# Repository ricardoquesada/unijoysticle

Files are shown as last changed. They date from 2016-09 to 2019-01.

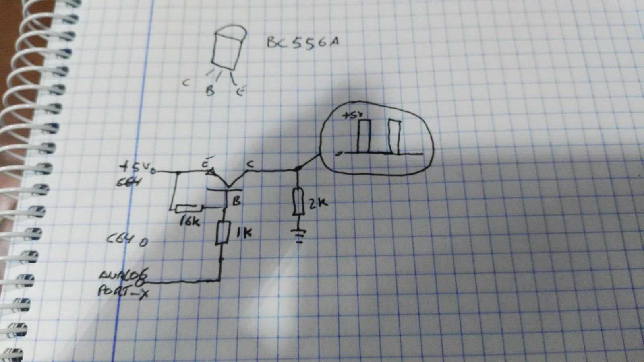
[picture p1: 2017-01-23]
schematic/unijoysticle_ultimate/maniako_filter.jpg

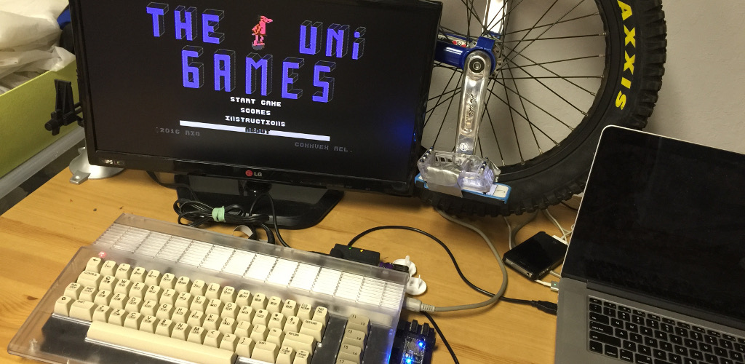
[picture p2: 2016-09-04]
client_android/store_images/feature_graphic.jpg

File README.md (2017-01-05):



# The UniJoystiCle

UniJoystiCle™

The UniJoystiCle, the ultimate unicycle simulator.

It allows you to play Commodore 64 [unicycle video games](https://github.com/ricardoquesada/c64-the-uni-games) with real unicycles. Unique immersive experience, much better than VR.

This repository contains:

* the [schematic + PCB board](https://github.com/ricardoquesada/unijoysticle/tree/master/schematic) to build your own Wi-Fi receiver
* the [firmware](https://github.com/ricardoquesada/unijoysticle/tree/master/esp8266_firmware) that runs on the Wi-Fi receiver
* the [iOS client](https://github.com/ricardoquesada/unijoysticle/tree/master/client_ios) / [Android client](https://github.com/ricardoquesada/unijoysticle/tree/master/client_android) / [Desktop client](https://github.com/ricardoquesada/unijoysticle/tree/master/client_desktop): they send the packets to the Wi-Fi receiver

UniJoystiCle v0.4

## Further info

* [Documentation](DOCUMENTATION.md)
* [Home page](http://retro.moe/unijoysticle)

## Videos

The Uni Games v0.4 (https://www.youtube.com/watch?v=ZLAgooXx4bo)

Game Controllers (https://www.youtube.com/watch?v=2lZSAKbrHTo)

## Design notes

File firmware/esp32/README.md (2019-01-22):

# Unijoysticle v2.0

Unijoysticle + bluetooth.

## About

Use modern bluetooth gamepads / mouse in old computers like the Commodore 64, Atari ST, Amiga 500, Apple 2, Tandy 1000, IBM PC Jr., Atari 800, etc.

## Status

Early develop stages. PoC working on PC. Need the rest.

- firmware works on PC.
- missing all the rest.

## Want to help ?

- Download libusb: https://libusb.info/ (needed to test on PC with bluetooth dongle).
- Download BlueKitchen: https://github.com/bluekitchen/btstack
- Download Unijoysticle code: https://gitlab.com/ricardoquesada/unijoysticle
- Get any bluetooth gamepad (iOS, Android, Xbox tested. PS4 not supported ATM)
- For ESP32:
  - Download ESP-IDF: https://github.com/espressif/esp-idf
  - Get an ESP32 module, like [the MH-ET Live][1] which is pin-compatible with [Wemos D1 Mini][2] (used by Unijoysticle v0.4.2 PCB).

### Compile BTstack

#### For PC/Linux/Mac development

- Install the Bluetooth USB dongle on your PC/Mac/Linux
- libusb: Compile and install. Don't use `master` tip-of-tree if you are on macOS. Use 1.0.22 or earlier
- bluekitchen: Compile the libusb port to make sure everything works.

```sh
$ cd src/btstack/port/libusb
$ make
$ ./gap_inquiry
```

Put your gamepad in bluetooth discovery mode and you should see it.

#### For ESP32 development
```sh
$ cd src/btstack/port/esp32
$ ./integrate_btstack.py
$ cd example/gap_inquiry
$ make menuconfig
$ make flash monitor
```
And just in case, read the `README.md` that is in the `src/btstack/port/esp32` folder.

Put your gamepad in bluetooth discovery mode and you should see it.

### Compile Unijoysticle

Once you know that BTStack is working as expected, you can try with the UniJoystiCle code.

For PC/Linux/Mac development:
```sh
$ cd src/unijoysticle/firmware/esp32/tools
$ make
./unijoysticle
```

For ESP32 development:
```sh
$ cd src/unijoysticle/firmware/esp32
$ make menuconfig
$ make flash monitor
```

Put the gamepad in discovery mode. The gamepad should be recognized and when you press buttons, you should see them on the console.

## What works:

- PC + Bluetooth dongle. Ideal for rapid development. Eastier to test new Bluetooth features and debug.
- Works on ESP32 as well
- It supports up until 4 gamepads at the same time.
- Discovery/Connect/Disconnect/Reconnects works
- Parses HID and identifies all possible gamepad buttons / pads / hats.

## What's missing

### Firmware:
- Create mapping code. Something that correctly maps the different gamepad buttons to the desired ones.
- Support Class / Extended modes:
   - Mode Classic: traditional modes with 1 or 2 gamepads (like one or two joysticks)
   - Mode extended: one gamepad controls 2 joysticks
- Test everything on esp32
  - Disable non required features like WiFi that it takes less current.
- Support mouse/pads: ideally a bluetooth mouse could be used.

### Hardware

- it is possible that the board could get current from the c64/atari's joystick ports?
- design new board, if possible one that doesn't use devkits
- lines for the C64 / Atari pots
- PC Jr. / Tandy 1000 / Apple II: investigate, they use analog lines

### Mobile application

- [Optional]: Simple Bluetooth application that connects to the host and allow us to configure it
  and see its status, etc.

[1]: https://www.aliexpress.com/item/MH-ET-LIVE-ESP32-MINI-KIT-WiFi-Bluetooth-Internet-of-Things-development-board-based-ESP8266-Fully/32819107932.html
[2]: https://wiki.wemos.cc/products:d1:d1_mini

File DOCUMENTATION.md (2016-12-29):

# The UniJoystiCle™ Documentation

* [About](#about)
* [The WiFi Device](#the-wifi-device)
* [The Smartphone client controller](#smartphone-client-application)
* [The Desktop client controller](#desktop-client-application)
* [The Protocol](#the-protocol)
* [Building the WiFi Device](#building-the-wifi-device)
* [Firmware Options](#firmware-options)
* [Troubleshooting](#troubleshooting)

## About
The UniJoystiCle is a unicycle simulator for the Commodore 64, and much more! It allows you to control the joystick lines remotely, with anything that you have in mind like:

* play c64 games using modern game controllers (Xbox, iOS or Android game controllers)
* play [The Uni Games](https://github.com/ricardoquesada/c64-the-uni-games), a c64 unicycle game, using a real unicycle
* automate your home from the C64 with the [Commodore Home](https://retro.moe/2016/10/31/retro-challenge-commodore-home/)
* and more!

It consists of two major parts:

* The UniJoystiCle WiFi device
* The UniJoystiCle client application: iOS, Android, Mac, Windows and Linux

## The WiFi device



The WiFi device goes attached to the Commodore 64, and is the one that generates the real joystick movements. It does so by opening/closing the joystick lines.

In order to work it needs power. Unfortunately the C64 joystick ports DON'T have enough current to power it. The options to power it are:

* Using the barrel jack:
  * a +5v DC with at least 320mA
  * Examples:
    * Getting power from the Datasette port [with a custom cable](http://store.go4retro.com/c2n-power/) (recommended, but might need a [PSU with enough amps](http://personalpages.tds.net/~rcarlsen/custom%20ps.html))
* Using the micro USB socket:
  * It can be connected to a computer
  * or using a wall charger



### Booting the WiFi device

* DO NOT plug the UniJoystiCle WiFi device to the Commodore 64 yet (if you plug it, you won't break anything, it is that it just might not boot)
* Power the UniJoystiCle WiFi device (see above)
* Wait a few seconds and you should see one LED. That means that the device booted, and you can connect to it.
  * If you don't see the one LED, please go to [Troubleshooting](#troubleshooting)
* Now, you can plug it to the Commodore 64

By default, the WiFi device will start in Access Point mode, and will create a WiFi network named "unijoysticle-xxyyzz". From your smartphone Settings, connect to it...:



...and then launch the UniJoystiCle smartphone app.

## Smartphone Client Application

The client application can be download for free from the App Store / Google Play:

<a href='https://play.google.com/store/apps/details?id=moe.retro.unijoysticle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'>Get it on Google Play</a>

It sends "joystick commands" to the WiFi device. These commands are regular joystick movements: _Up_, _Down_, _Left_, _Right_ and _Fire_. It can send one or multiple commands at the time.

There are five modes: _UniJoystiCle mode_, _D-pad mode_, _Commando mode_, _Gyruss mode_ and _Commodore Home mode_.



### UniJoystiCle mode

      

In this mode, the joystick commands are generated from the smartphone's accelerometer. The accelerometer detects acceleration in the three coordinates: X, Y and Z. If we attach an accelerometer (in this case the smartphone) to a unicycle (or bike) pedal, and we measure the accelerometer's data while we pedal, we will notice that the X and Z axis generates data similar to a sine and cosine.



And if we put those values in cartesian coordinates (eg: Accelerometer(Z) = Y axis, and Accelerometer(X) = X axis), we will have something similar to a circle.



And if we calculate the arctangent (`atan2()`) value of sin/cosine we get the angle. And with the angle we can simulate the joystick movements. We divide the circle in 8 segments, and assign a joystick movement to each segment. Eg:



There are no such things as "joystick diagonal commands". So in order to simulate the top-right diagonal, we just send the "top" and "right" joystick movements at the same time.

From the graphic we can deduce that:
<p style="padding-left: 30px;"><strong>One pedal revolution == one joystick "revolution"</strong></p>
But it is possible to change that ratio. For example, we can change it to "One pedal revolution == <strong>two</strong> joystick revolutions". Just go to settings and do:



A ratio of 2.0 will divide the circle in 16 segments (8 segments * 2.0 ratio == 16 segments), and what will happen is that:
<p style="padding-left: 30px;">One pedal revolution == Two joystick revolutions</p>



This is useful to:

* Increase your speed when you have an slow unicycle (eg: long cranks or big wheel size), or you don't pedal fast enough
* You want to play face-to-face with another rider, but one has an slower unicycle

__Firing:__ In order to _fire_, you have to hop. Settings has a "Jump Threshold" settings that is used to control how hard you have to hop.

__Compatibility:__ This mode is compatible with multiple sports games like:

* [The Uni Games](https://github.com/ricardoquesada/c64-the-uni-games) (in fact this mode was created to play this game)
* Sports games like [Hypersports](http://gamebase64.com/game.php?id=3666&d=18&h=0), [Decathon](http://gamebase64.com/game.php?id=2057&d=18&h=0), etc.
* [C64anabalt](http://www.rgcd.co.uk/2011/12/c64anabalt-c64-2011.html), and other jump-only-games
* and more

__Video:__ [Using a unicycle to play The Uni Games ](https://www.youtube.com/watch?v=w2cdoTU-GJU)

__Video:__ [Using one foot to play C64anabalt](https://www.youtube.com/watch?v=n7p1p53uisk)

### D-pad mode



This mode converts the smartphone in a virtual D-pad. Just press the arrows for joysticks movements, and the circle to fire.

__Compatibility:__

* Any game can be played in this mode.

__Using this mode:__ [YouTube video](https://youtu.be/RhEGogreM0E)

### D-pad + Game Controllers



This is the same D-pad mode as before. But if you <a href="http://www.howtogeek.com/242223/how-to-use-a-physical-game-controller-with-an-iphone-ipad-or-android-device/">connect any Game Controller to your smartphone</a> (for iOS it supports both <a href="https://afterpad.com/mficontrollers/">MFi</a> and <a href="https://www.ionaudio.com/products/details/icade">iCade</a> controllers; for Android it supports official controllers as well as OUYA ones), it will automatically detect it. And with it you can control the virtual D-pad giving you a great gaming experience.

You can configure it to:

* Use Button "B" to jump. When enabled, it will disable to "Up" D-pad arrow
* Swap Buttons "A" and "B" (swaps Jump and Shoot buttons)



__Compatibility:__

* Any game can be played in this mode.
* Optimized for platformer games like [Giana Sisters](http://gamebase64.com/game.php?id=3275&amp;d=18&amp;h=0), [Super Bread Box](http://gamebase64.com/game.php?id=24140&amp;d=18&amp;h=0), [Bubble Bobble](http://gamebase64.com/game.php?id=1138&amp;d=18&amp;h=0), etc.

__Using this mode:__ [YouTube video](https://www.youtube.com/watch?v=0cdgaYVYaao)

__Which controller should you use:__

For iOS:
* For MFi controllers, try here: [AfterPad](https://afterpad.com/mficontrollers/">https://afterpad.com/mficontrollers/). The [Nimbus SteelSeries](https://afterpad.com/steelseries-nimbus-the-afterpad-review/) is good. DO NOT get the Status SteelSeries.
* For iCade controlles, try here: [iCade Controllers](http://retrorgb.com/icadecontrollers.html). The ["original" iCade](http://retrorgb.com/icade.html) is good.

For Android:
* Any Game Controller that supports __the Android protocol__. See [reviews here](http://www.androidauthority.com/best-bluetooth-gaming-controllers-403184/) [and here](https://www.slant.co/topics/2074/~third-party-game-controllers-for-android)
* OUYA Game Controllers (they are not that great though). [Get it here](http://www.ebay.com/sch/i.html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)
* Notes:
  * Amazon Fire Game Controllers support the Android protocol
  * Moga Game Controllers support the Android protocol [when in "B" mode](https://gavinsgadgets.com/2016/03/21/how-to-connect-a-moga-pro-power-bluetooth-game-controller-with-the-samsung-galaxy-s7/)
  * WiFi-Direct game controllers are supported as well, like the NVIDIA SHIELD, or the Amazon Fire 2nd gen. But since most smartphones don't support WiFi-Direct, you should install the Android UniJoystiCle app into WiFi-Direct-enabled devices, like the Amazon Fire TV, or the NVIDIA SHIELD Android TV.

### Commando mode + Game Controllers



In this mode you control both joysticks at the same time. A game controller is needed for this. Can't be played with the "virtual" dpad.
It is called "Commando" mode, since it allows you to play games like Commando, Turrican II or Dropzone since:

* The dpad and the left stick are mapped to Joystick #2 direction movements
* The right stick is mapped to Joysticke #1 directional movements
* Button A is mapped to Joystick #2 Fire
* Button B is mapped to Joystick #1 Fire
* Button X is mapped to Joystick #1 Down
* Button Y is mapped to Joystick #1 Rigth

For example:

 * in Commando you can throw grenades by pressing button B.
 * in Turrican II you can trigger the power lines by pressing button B, and trigger the super weapon by pressing button A and B simultaneously
 * in Dropzone you can use button B to throw bombs and button X to active cloak

__Compatibility:__

* Any game that uses Joystick #2 + spacebar can be used in this mode. eg: [Commando](http://gamebase64.com/game.php?id=1602&d=18&h=0), [Turrican II](http://gamebase64.com/game.php?id=8234&d=18&h=0), [Dropzone](http://gamebase64.com/game.php?id=2362&d=18&h=0)
* Any dual player game can be played in this mode.

__Using this mode:__ [YouTube video](https://www.youtube.com/watch?v=VK-gzT5wkiw)

__Which controller should you use:__

Refer to _D-pad + Game Controllers_ section.

### Gyruss mode



In this mode you control the black circle that is inside the blue circle strip. You move the black ball by tilting your smartphone, and gravity will do the rest. Press the gray circle at the right for _fire_.



__Compatibility:__

* [Gyruss](http://gamebase64.com/game.php?id=3370&d=18&h=0)
* all the <em>UniJoystiCle mode</em> games
* and games with similar techniques to Gyruss

__Using this mode:__ [YouTube video](https://youtu.be/n2YHoj1pXB8)

__Note__: This mode is only avaible on iOS. Android support coming soon.

### Commodore Home mode



__Compatibility:__

* [Commodore Home](https://retro.moe/2016/10/31/retro-challenge-commodore-home/), home automation for the masses, not the classes

__Using this mode:__ [YouTube video](https://www.youtube.com/watch?v=wH3g09zsTdY)

## Desktop Client Application

The desktop application can be downloaded from here:

* Mac: [UniJoystiCle Controller.dmg](http://ricardoquesada.github.io/unijoysticle/bin/UniJoystiCle%20Controller-v0.4.2.dmg)
* Win32: [unijoysticle_controller.win32.zip](http://ricardoquesada.github.io/unijoysticle/bin/unijoysticle_controller-v0.4.2.win32.zip)

It supports three modes:

* Dpad mode
* Commando mode
* Commodore Home mode

### Dpad mode



It can be used with a game controller, or with the keyboard.
For win32, it supports any Xinput controller (like the xbox 360 controllers), and for Mac, it supports any MFi controller.
The keyboard mapping is:

* cursor arrows: directional movement
* `z`: button A
* `x`: button B

### Commando mode



It can be used with a game controller, or with the keyboard.
For win32, it supports any Xinput controller (like the xbox 360 controllers), and for Mac, it supports any MFi controller.
The keyboard mapping is:

* `a`, `s`, `d`, `w`: Joy #1 directional movement
* `x`: Joy #1 fire
* `j`, `k`, `l`, `i` and cursor arrows: Joy #2 direction movement
* `z`: Joy #2 fire

### Commodore Home mode



__Compatibility:__

* [Commodore Home](https://retro.moe/2016/10/31/retro-challenge-commodore-home/), home automation for the masses, not the classes

## The Protocol

You can create your own UniJoystiCle controller. Your controller just needs to "speak" the UniJoystiCle protocol, which is very simple.

The WiFi receiver listens to UDP port 6464 and it expects a packet of 4 bytes:
```
+----+----+----+----+
|ver |mode|joy1|joy2|
+----+----+----+----+

byte 0, version: must be 2
byte 1, mode: contains state for which joysticks?. 1=joy1, 2=joy2, 3=joy1 and joy2
byte 2, joy1 state
byte 3: joy2 state
```

Joystick state values:
* bit 0: Joystick up enable/disable
* bit 1: Joystick down enable/disable
* bit 2: Joystick left enable/disable
* bit 3: Joysticke right enable/disable
* bit 4: Joysticke fire enable/disable
* bits 5,6,7: unused

Example, a packet with these bytes means:

```
0x02, 0x03, 0x11, 0x1f
```

* byte 0 = 0x02
* byte 1 = 0x03: It means the both joy1 and joy2 states are being sent
* byte 2 = 0x11 = %00010001 = It means that both fire and up are enabled. the rest are disabled
* byte 3 = 0x1f = %00011111 = It means that all lines are enabled: up, down, left, right and fire

## Building the WiFi device

### Assembling the PCB

The hardware as well as the software are open source. So you can build one yourself. The schematic and board files are in [Eagle](https://cadsoft.io/) format:

* board: <a href="https://github.com/ricardoquesada/unijoysticle/blob/master/schematic/unijoysticle.brd">unijoysticle.brd</a> (v0.4.1)
* schematic: <a href="https://github.com/ricardoquesada/unijoysticle/blob/master/schematic/unijoysticle.sch">unijoysticle.sch</a> (v0.4.1)

You will need the following components (BOM):

* 1 x Wemos D1 Mini device. Any of these devices:
  * [Wemos D1 Mini v2](https://www.aliexpress.com/store/product/D1-mini-Mini-NodeMcu-4M-bytes-Lua-WIFI-Internet-of-Things-development-board-based-ESP8266/1331105_32529101036.html)
  * or [Wemos D1 Mini Pro](https://www.aliexpress.com/store/product/WEMOS-D1-mini-Pro-16M-bytes-external-antenna-connector-ESP8266-WIFI-Internet-of-Things-development-board/1331105_32724692514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)
* 2 x [DB9 female](https://www.digikey.com/product-detail/en/assmann-wsw-components/A-DF-09-A-KG-T2S/AE10921-ND/1241800)
* 3 x [4066 IC](https://www.digikey.com/product-detail/en/texas-instruments/SN74HC4066N/296-8329-5-ND/376726)
* 3 x [sockets for the ICs](https://www.digikey.com/product-detail/en/on-shore-technology-inc/SA143000/ED3014-ND/3313545)
* 1 x [barrel jack](https://www.digikey.com/product-detail/en/cui-inc/PJ-002A/CP-002A-ND/96962)
* 1 x [1N4001 diode](https://www.digikey.com/product-detail/en/micro-commercial-co/1N4001-TP/1N4001-TPMSCT-ND/773688)

And solder them. It should be straightforward where to place the components. If not, [ping me](https://twitter.com/ricardoquesada)

The barrel jack and the diode are optional. They are needed if you want to power the device from an external power source. eg: from the C64 datasette port. Any +5v DC power with at least 320mA should be enough.
If you want to avoid the soldering, you can __[order an already assembled PCB from here](https://retro.moe/unijoysticle/)__.

After assembling the PCB, it should look like this:





### Instaling the firmware
* Make sure that the UniJoystiCle Wifi device is NOT plugged into the C64
* Connect the UniJoystiCle Wifi device to the computer using the micro USB cable
* If you are using the Wemos D1 Mini v2:
   * Install the [CH340 USB-to-UART driver](https://www.wemos.cc/downloads)
   * For macOS Sierra, [follow these instructions](https://tzapu.com/ch340-ch341-serial-adapters-macos-sierra/)
* If you are using the Wemos D1 Mini Pro:
   * Install the [CP2104 USB-to-UART driver](http://www.silabs.com/products/mcu/pages/usbtouartbridgevcpdrivers.aspx)

And from here you have two options: the "easy" one for users, and the "hard" one for developers:

#### Option A: For users only

Either you can use:
* [esptool.py](https://github.com/themadinventor/esptool) (a CLI tool for Windows, Linux and Mac)
* or [NodeMCU flasher](https://github.com/nodemcu/nodemcu-flasher) a GUI tool (Windows only)

For `esptool.py` you should do:

* Download the latest UniJoystiCle firmware from here: [unijoysticle_firmware.bin](http://ricardoquesada.github.io/unijoysticle/bin/unijoysticle_firmware.bin)
* Install [esptool](https://github.com/themadinventor/esptool)
  * `$ pip install esptool`
* Execute: `$ sudo python esptool.py --port /dev/cu.SLAB_USBtoUART write_flash -fm dio -fs 32m 0x00000 /path/to/unijoysticle_firmware.bin`

In case it is needed, it uses a:
  * ESP8266-12e module
  * It has a 4Mbyte (32Mbit) flash
  * use 0x00000000 as offset

For detailed info, read: [Flashing the NodeMCU firmware](https://nodemcu.readthedocs.io/en/dev/en/flash/)

Since firmware v0.4.2, manual upgrading no longer needed to. It has an option to upgrade itself.

#### Option B: For developers only
* Install [PlatformIO](http://platformio.org)
* Clone the [UniJoystiCle github repo]("https://github.com/ricardoquesada/unijoysticle)
* And do `make && make upload`

Example:
```
$ git clone https://github.com/ricardoquesada/unijoysticle.git
$ cd unijoysticle/esp8266_firmware/firmware
$ make
$ make upload
```
## Firmware options



<a href="https://lh3.googleusercontent.com/GVWA4EnXclCFhNujWICYYmkRutvAdIUkPNW1X3dhdErm_LzYRWgoN1k_7n8xzdTlZNA6QjPF6NPu5FbpZSIHVoLCFT8RFHQs2geO2JHHv_Fj_gS4c265_htPTTEUIiO57DM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"><small></small>_Click here to enlarge_</small></a>

  * __A__: Use [http://unijoysticle.local/](http://unijoysticle.local/) to access the firmware options
  * __B__: Stats, includes: IP Address, firmware version, and other status
  * __C__: WiFi modes:
     * Access Point mode: default mode. Creates its own WiFi network
     * Station mode: uses SSID/password to join the WiFi network
     * Station mode + WPS: Uses WPS to join a network
  * __D__: Set the SSID/password here in order to use Station mode
  * __E__: Inactivity timeout. Default: 10 secodns. After N seconds of inactivity, the joystick state will be reset
  * __F__: Multicast DNS name. Default: "unijoysticle.local". Useful if you want to have more than one UniJoystiCle device in the same network
  * __G__: To reboot the device
  * __H__: Press here in order to upgrade the firmware

## Troubleshooting

The first thing to do: download and run this C64 program. Then follow its intructions:

  * [UniJoystiCle test program](https://github.com/ricardoquesada/unijoysticle/raw/master/tests/bin/unijoysticle_test_exo.prg)



### The device (Wemos D1 Mini) doesn't boot

If you don't see one LED on the device then:

* Make sure it is NOT plugged into the Commmodore 64
* Power it either:
  * via the micro USB cable
  * or by using the barrel jack: a +5V with __at least 320mA__ should be Ok.
* Press the RESET button on the Wemos D1 Mini device

If that doesn't work (you don't see the one LED), probably:

* try booting it again. Just press the `RESET` button that is in the device
* or perhaps your device doesn't have the UniJoystiCle firmware. Go to the "Installing the firmware" section
* you are using power from c64 (datasette, user port or expansion port), and the C64 doesn't have enough current. See [When using power from the C64](#when-using-power-from-the-c64))

#### When using power from the C64

You should know that all the connected devices compete for the current. Example: If you have an 1541 Ultimate II, a WiModem and the UniJoystiCle, then the three of them will compete for current. If that is the case, most probably one of them won't work.

Tested configurations with __current taken from the datasette port__:

* UniJoystiCle + regular c64 PSU + C64: Works Ok.
* UniJoystiCle + 1541 Ultimate II + regular c64 PSU + c64: Works Ok.
* UniJoystiCle + Turbo Chameleon 64 + regular c64 PSU + c64: Sometimes it works, sometimes it doesn't
* UniJoystiCle + Turbo Chameleon 64 + [Ray Carlen's PSU](http://personalpages.tds.net/~rcarlsen/custom%20ps.html) + c64: Works Ok
* UniJoystiCle + Turbo Chameleon 64 + WiModem + [Ray Carlen's PSU](http://personalpages.tds.net/~rcarlsen/custom%20ps.html) + c64: Works Ok
* UniJoystiCle + C128D: Works Ok

#### So, How much power does The UniJoystiCle use ?

The WiFi module alone uses up to 200mA when it is in Access Point and the clients try to connect to it. But on average it uses ~56mA. More info here: [ESP8266 Power Consumption](http://bbs.espressif.com/viewtopic.php?t=133).
It also uses 12mA for each joystick line that is High. For example, if 3 lines are High (Joy #1 Up, Joy #1 Fire, joy #Left) then it will use 36mA for that alone.
So, a max of 320mA might be needed:

* Up to 200mA for the WiFi module (but the average ~56mA)
* plus 120mA when all ten joystick lines are High

### Joysticks don't work

* From your smartphone, make sure that you are connected to the Unijoysticle WiFi network
  * If it fails to connect, try again. Sometimes it take a few tries to connect
  * No more than 2 connections will be accepted (at least in firmware 0.3.1)
* From the smartphone UniJoystiCle application, make sure that the WiFi device address is:
  * `192.168.4.1` (when in Access Point mode)
  * or `unijoysticle.local` (which will work both for Access Point and Station modes)

### The C64 keyboard doesn't work

This is because the UniJoystiCle smartphone application is sending joystick commands to the C64.
Just make sure that the UniJoystiCle smartphone application is not running.

This is not a bug/limitation of the UniJoystiCle. It is a c64 limitation.
The c64 keyboard won't work correctly if you keep moving a regular joystick while using the keyboard.

Since firmware v0.4.3, a default inactivity timeout of 10 seconds was added.
If no data is received within that period of time, the joysticks are going to be reset.

### The game controllers don't work

* For iOS, both MFi and iCade (the "old" unofficial) game controllers should work.
* For Android, any official (including Amazon, Nvidia, Moga game controllers) and the OUYA game controllers should work.
* For Windows, any Xinput-based (the new joystick API) controller should work, like the Xbox 360. If you have a DirectInput-based game controller, try using [x360ce](http://www.x360ce.com/)
* For Mac, any MFi game controllers are supported.
* Make sure that the Game Controller is paired via Bluetooth to the smartphone / PC / Mac.
  * If unsure, [read this guide](http://www.howtogeek.com/242223/how-to-use-a-physical-game-controller-with-an-iphone-ipad-or-android-device/)
* When the game controller is paired to the smartphone/PC/Mac, you can use it in the D-pad and Commando modes:
  * on iOS you should see a legend that says "Game controller detected" (MFi controllers). Or nothing if using iCade controllers.
  * on Android you should see the name of the game controller in the title
  * on Mac/Windows, you should see "Game controller: Connected" on the status bar (bottom-left)

### Some joystick movements work but others don't

* Probably one (or more) of the 4066 ICs are malfunctioning. Try swapping them until you find the broken one. And then replace it with a new one
* or perhaps one of the traces in the PCB is open. With a multimeter and the schematic you should be able to find it.

## Bugs

Did you find a bug? Please report it here:

* [UniJoystiCle Bugs](https://github.com/ricardoquesada/unijoysticle/issues)

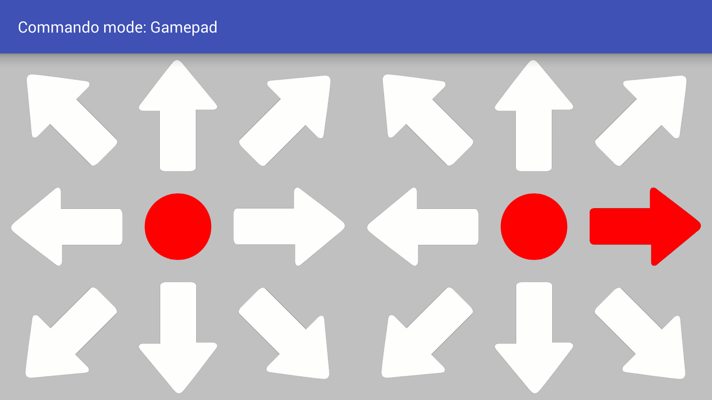
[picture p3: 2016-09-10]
client_android/store_images/screenshot_commando_mode.png

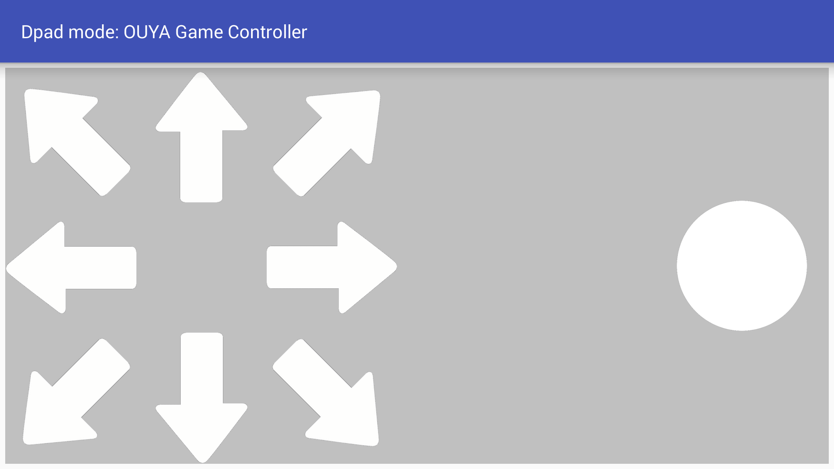
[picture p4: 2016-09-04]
client_android/store_images/screenshot_dpad_mode_ouya.png

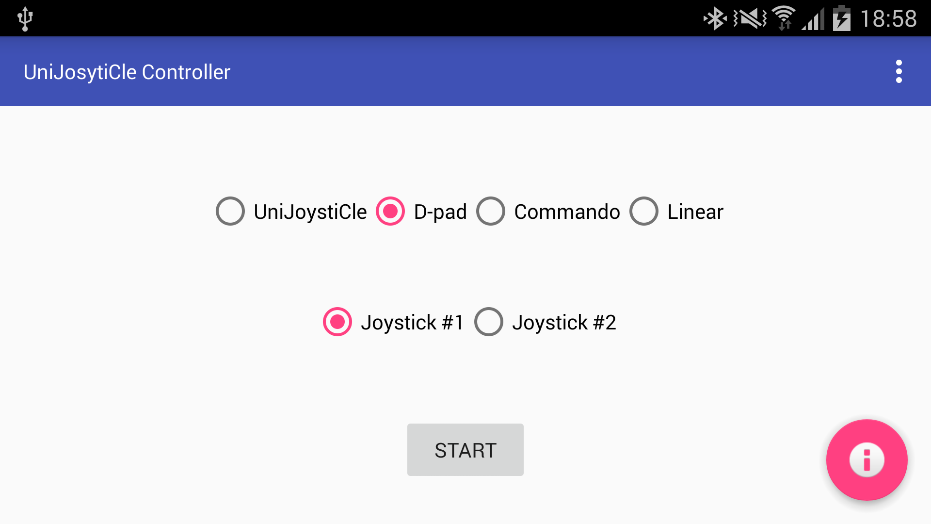
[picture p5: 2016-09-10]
client_android/store_images/screenshot_main.png

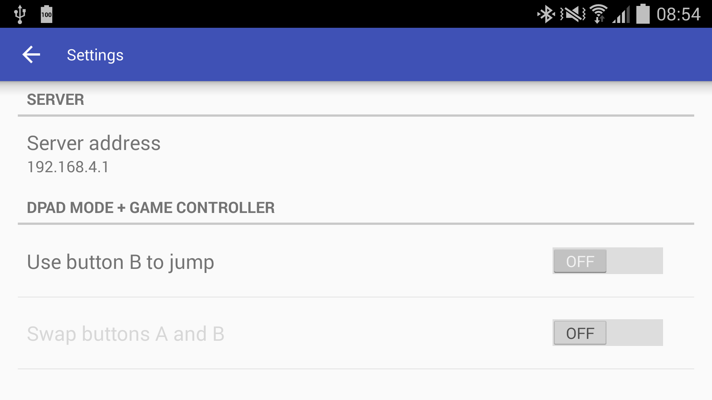
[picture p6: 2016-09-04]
client_android/store_images/screenshot_settings.png

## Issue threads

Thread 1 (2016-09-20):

When connected using USB cable, device might not boot

ricardoquesada, 2016-09-20:
To boot the NodeMCU make sure that it is not connected to the Commodore 64. Otherwise it might not boot. I guess (big guess) it is related to a line that should be floating, but it is not when it is connected to the C64. Apparently it only happens when it is powered via USB.

When begin powered with the external power supply, it seems that it can boot without problem.

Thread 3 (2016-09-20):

Device is not compatible with 128D and SX64 since the WiFi controller doesn't fit.

ricardoquesada, 2016-09-20:
It is only compatible with Commodore 64, 64c and 128.
But it doesn't fit in the C128D and the SX64.
And smaller PCB is needed.

ricardoquesada, 2016-11-08:
fixed in v0.4.0rc

Closed 2016-11-08.

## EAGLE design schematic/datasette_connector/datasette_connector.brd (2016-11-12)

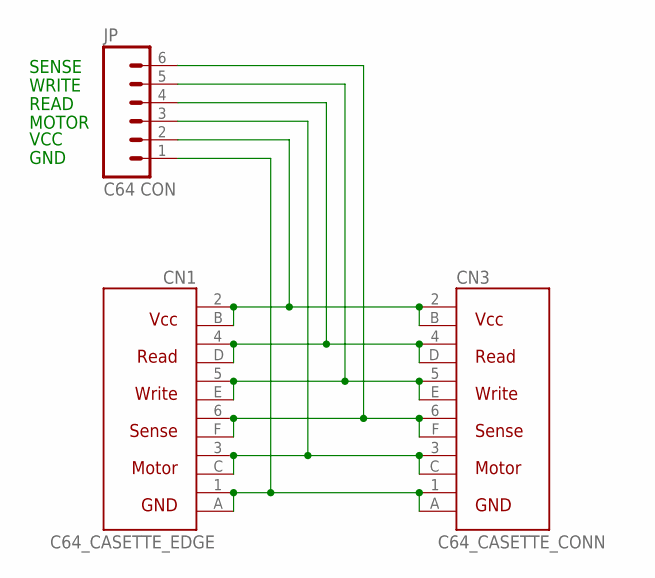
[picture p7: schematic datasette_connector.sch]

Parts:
CN1: C64_CASETTE_EDGE; C64_CASSETTE
CN3: C64_CASETTE_CONN; C64_CASSETTE_CONN
JP: C64 CON; 1X06_LOCK_LONGPADS

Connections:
GND: CN1.1 (GND1), CN1.A (GND2), CN3.1 (GND1), CN3.A (GND2), JP.1
unnamed: CN1.5 (WRITE1), CN1.E (WRITE2), CN3.5 (WRITE1), CN3.E (WRITE2), JP.5
unnamed: CN1.6 (SENSE1), CN1.F (SENSE2), CN3.6 (SENSE1), CN3.F (SENSE2), JP.6
unnamed: CN1.3 (MOTOR1), CN1.C (MOTOR2), CN3.3 (MOTOR1), CN3.C (MOTOR2), JP.3
unnamed: CN1.4 (READ1), CN1.D (READ2), CN3.4 (READ1), CN3.D (READ2), JP.4
VCC: CN1.2 (VCC1), CN1.B (VCC2), CN3.2 (VCC1), CN3.B (VCC2), JP.2

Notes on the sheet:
SENSE
WRITE
READ
MOTOR
VCC
GND

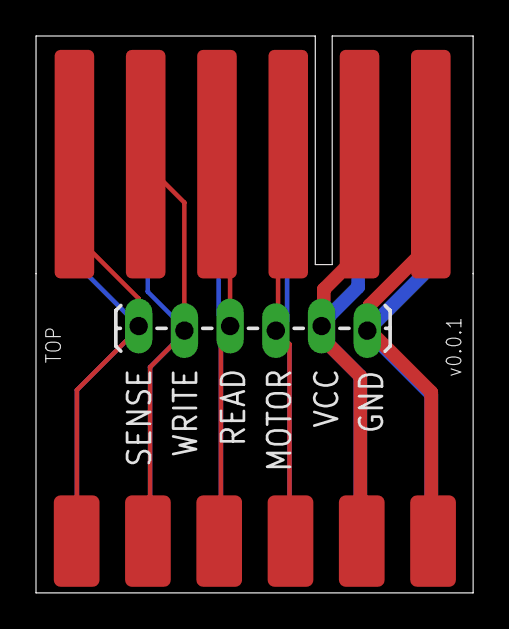
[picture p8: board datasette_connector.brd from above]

Board: 2 copper layers, 24.3 x 30.9 mm, 3 parts (1 on the bottom side), 6 nets.

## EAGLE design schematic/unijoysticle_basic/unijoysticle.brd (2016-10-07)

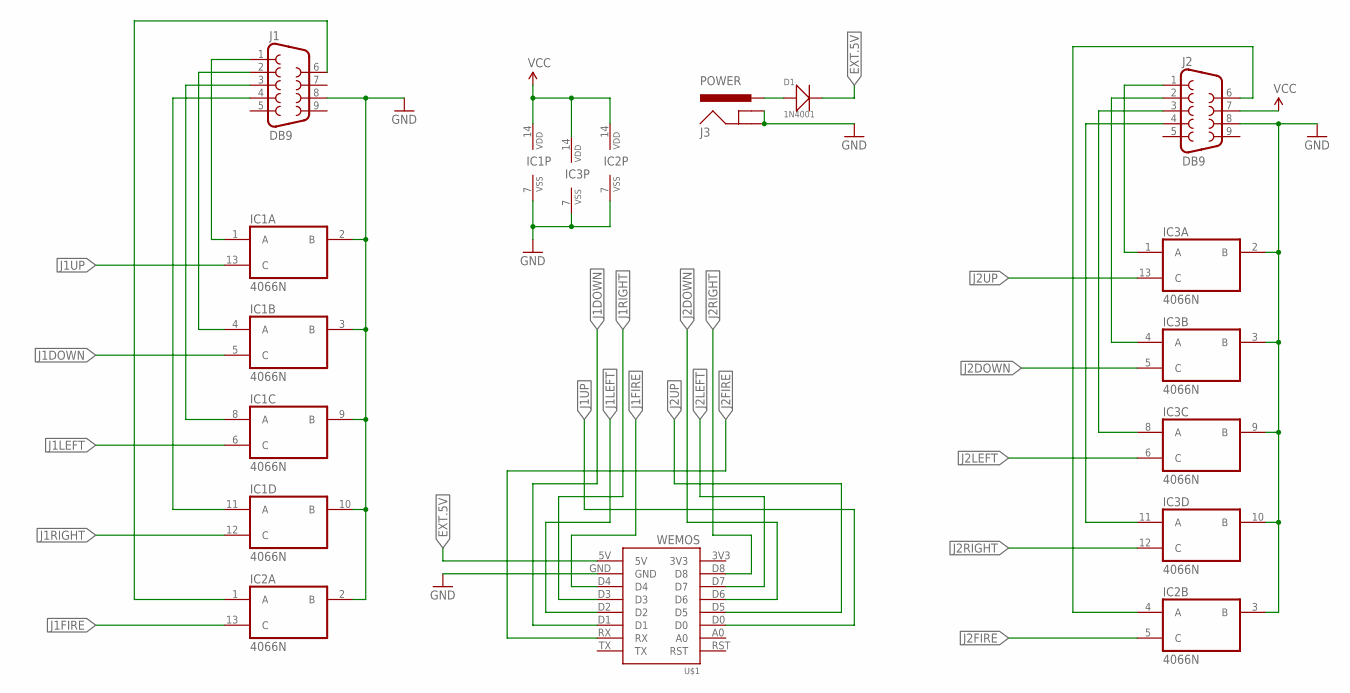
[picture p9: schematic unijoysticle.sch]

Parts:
D1: 1N4001; DO-41
IC1, IC2, IC3: 4066N; DIL14; MPN SN74HC4066N
J1, J2: DB9; MPN 618009231121
J3: POWER; POWER_JACK_SLOT
U$1: WEMOS

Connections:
EXT.5V: D1.2 (-), U$1.5V
GND: IC1.2 (B), IC1.3 (B), IC1.7 (VSS), IC1.9 (B), IC1.10 (B), IC2.2 (B), IC2.3 (B), IC2.7 (VSS), IC3.2 (B), IC3.3 (B), IC3.7 (VSS), IC3.9 (B), IC3.10 (B), J1.8, J2.8, J3.GND@1 (GNDBREAK), J3.GND@2 (GND), U$1.GND
J1DOWN: IC1.5 (C), U$1.D1
J1FIRE: IC2.13 (C), U$1.D4
J1LEFT: IC1.6 (C), U$1.D2
J1RIGHT: IC1.12 (C), U$1.D3
J1UP: IC1.13 (C), U$1.D0
J2DOWN: IC3.5 (C), U$1.D6
J2FIRE: IC2.5 (C), U$1.RX
J2LEFT: IC3.6 (C), U$1.D7
J2RIGHT: IC3.12 (C), U$1.D8
J2UP: IC3.13 (C), U$1.D5
unnamed: D1.1 (+), J3.PWR
unnamed: IC1.1 (A), J1.1
unnamed: IC1.4 (A), J1.2
unnamed: IC1.8 (A), J1.3
unnamed: IC1.11 (A), J1.4
unnamed: IC3.1 (A), J2.1
unnamed: IC3.4 (A), J2.2
unnamed: IC3.8 (A), J2.3
unnamed: IC3.11 (A), J2.4
unnamed: IC2.1 (A), J1.6
unnamed: IC2.4 (A), J2.6
VCC: IC1.14 (VDD), IC2.14 (VDD), IC3.14 (VDD), J2.7

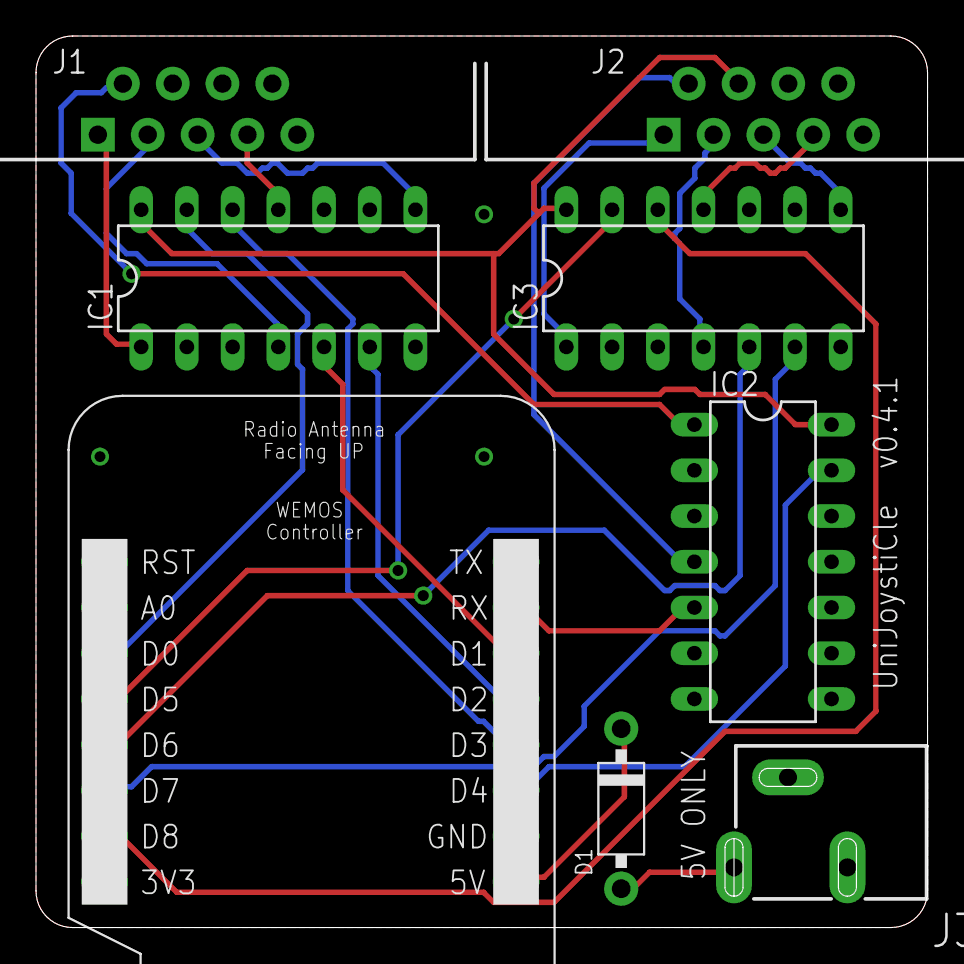
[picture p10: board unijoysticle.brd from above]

Board: 2 copper layers, 49.5 x 49.5 mm, 8 parts (0 on the bottom side), 24 nets.

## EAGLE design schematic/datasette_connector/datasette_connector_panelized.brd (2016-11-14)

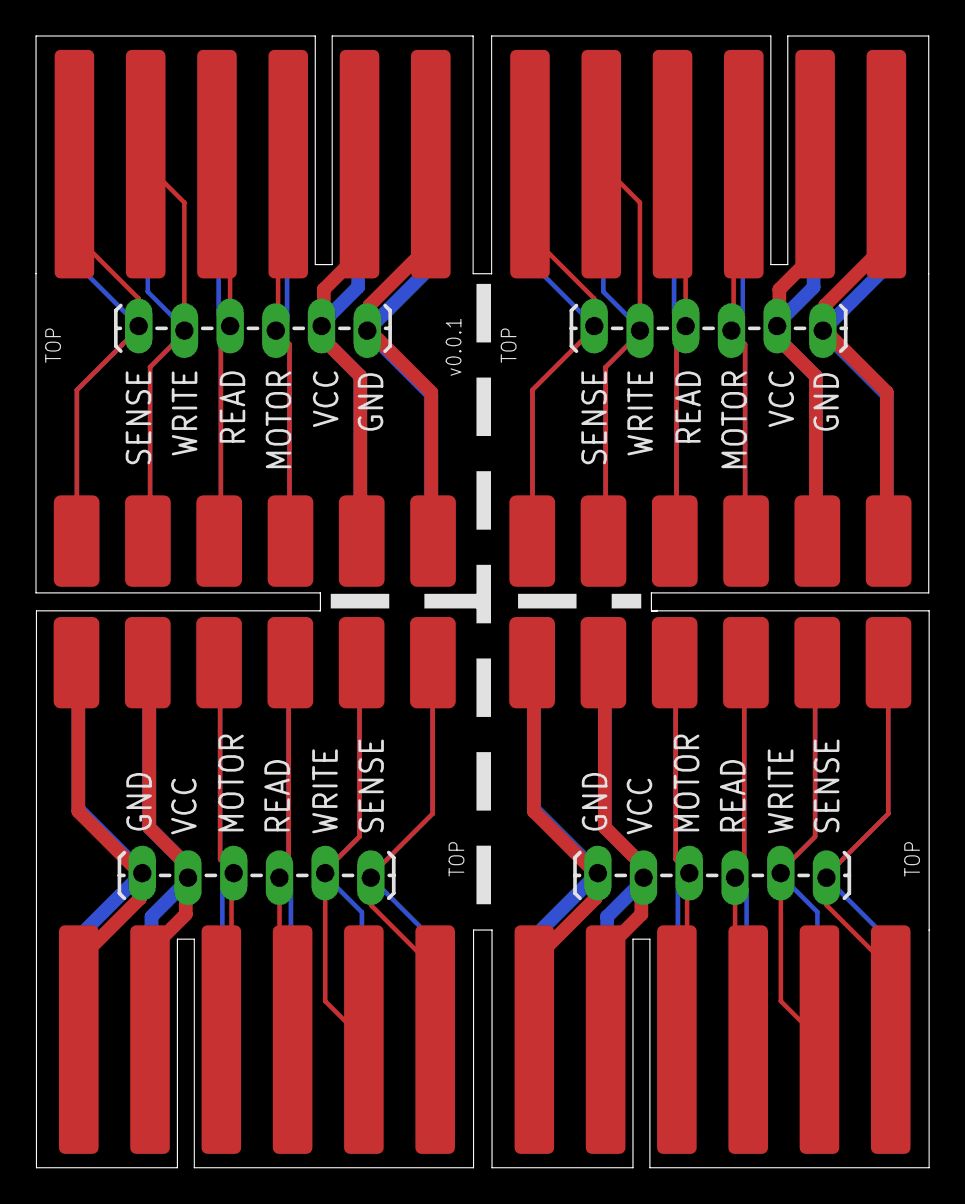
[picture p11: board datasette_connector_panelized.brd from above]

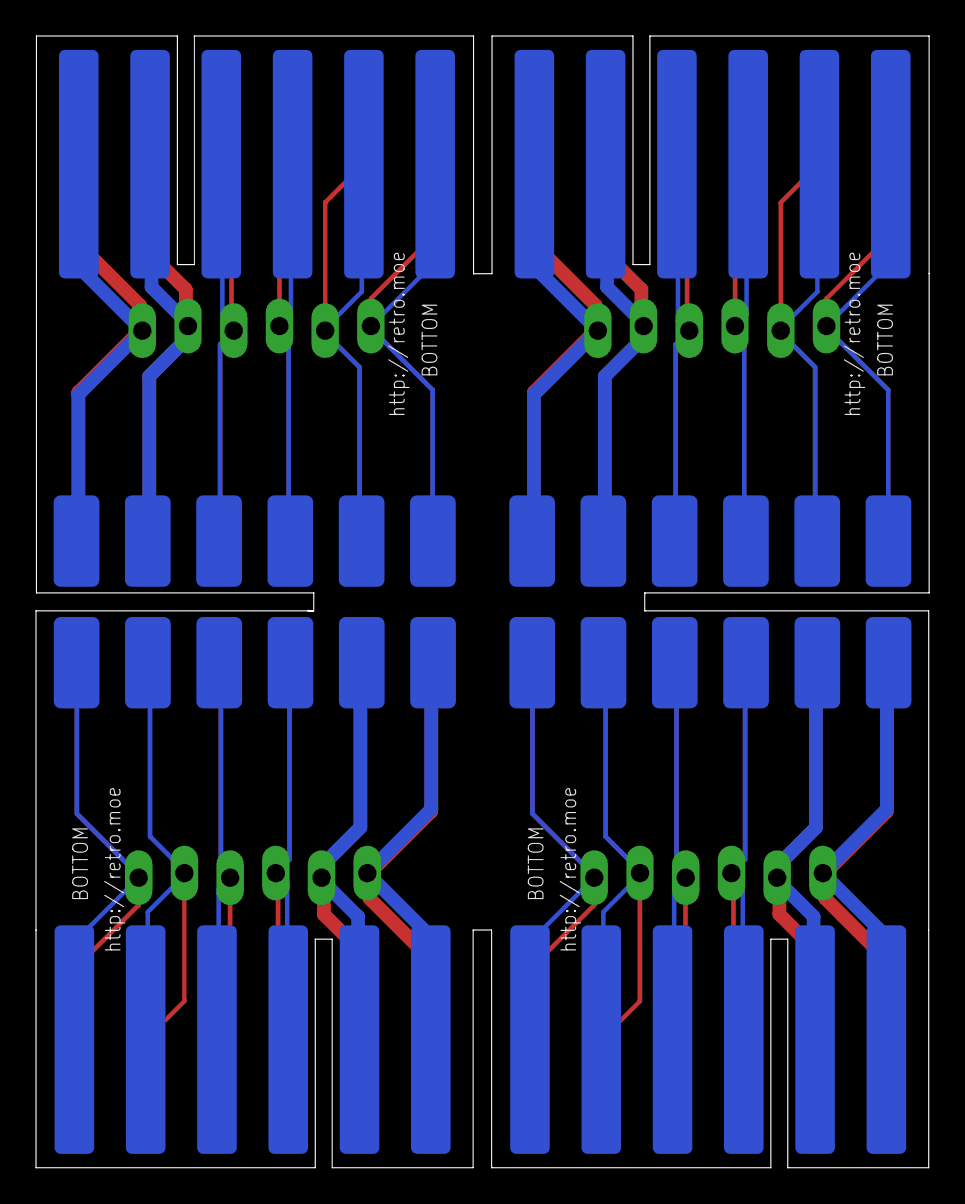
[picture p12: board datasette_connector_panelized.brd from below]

Board: 2 copper layers, 49.6 x 62.9 mm, 12 parts (4 on the bottom side), 24 nets.

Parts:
CN1, CN11, CN12, CN13: C64_CASETTE_EDGE; C64_CASSETTE
CN3, CN31, CN32, CN33: C64_CASETTE_CONN; C64_CASSETTE_CONN
JP, JP1, JP2, JP3: C64 CON; 1X06_LOCK_LONGPADS

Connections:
GND: CN1.1, CN1.A, CN3.1, CN3.A, JP.1
GND1: CN11.1, CN11.A, CN31.1, CN31.A, JP1.1
GND2: CN12.1, CN12.A, CN32.1, CN32.A, JP2.1
GND3: CN13.1, CN13.A, CN33.1, CN33.A, JP3.1
unnamed: CN1.5, CN1.E, CN3.5, CN3.E, JP.5
unnamed: CN1.6, CN1.F, CN3.6, CN3.F, JP.6
unnamed: CN1.3, CN1.C, CN3.3, CN3.C, JP.3
unnamed: CN11.5, CN11.E, CN31.5, CN31.E, JP1.5
unnamed: CN12.5, CN12.E, CN32.5, CN32.E, JP2.5
unnamed: CN13.5, CN13.E, CN33.5, CN33.E, JP3.5
unnamed: CN1.4, CN1.D, CN3.4, CN3.D, JP.4
unnamed: CN11.6, CN11.F, CN31.6, CN31.F, JP1.6
unnamed: CN12.6, CN12.F, CN32.6, CN32.F, JP2.6
unnamed: CN13.6, CN13.F, CN33.6, CN33.F, JP3.6
unnamed: CN11.3, CN11.C, CN31.3, CN31.C, JP1.3
unnamed: CN12.3, CN12.C, CN32.3, CN32.C, JP2.3
unnamed: CN13.3, CN13.C, CN33.3, CN33.C, JP3.3
unnamed: CN11.4, CN11.D, CN31.4, CN31.D, JP1.4
unnamed: CN12.4, CN12.D, CN32.4, CN32.D, JP2.4
unnamed: CN13.4, CN13.D, CN33.4, CN33.D, JP3.4
VCC: CN1.2, CN1.B, CN3.2, CN3.B, JP.2
VCC1: CN11.2, CN11.B, CN31.2, CN31.B, JP1.2
VCC2: CN12.2, CN12.B, CN32.2, CN32.B, JP2.2
VCC3: CN13.2, CN13.B, CN33.2, CN33.B, JP3.2

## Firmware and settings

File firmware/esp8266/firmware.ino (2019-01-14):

/****************************************************************************
http://retro.moe/unijoysticle

Copyright 2016 Ricardo Quesada

Licensed under the Apache License, Version 2.0 (the "License");
you may not use this file except in compliance with the License.
You may obtain a copy of the License at

    http://www.apache.org/licenses/LICENSE-2.0

Unless required by applicable law or agreed to in writing, software
distributed under the License is distributed on an "AS IS" BASIS,
WITHOUT WARRANTIES OR CONDITIONS OF ANY KIND, either express or implied.
See the License for the specific language governing permissions and
limitations under the License.
****************************************************************************/

// based on http://www.esp8266.com/viewtopic.php?f=29&t=2222


#define UNIJOYSTICLE_VERSION "v0.4.5"

// Newer esp8266 come with WPS disabled by default, and you won't be able to
// link. If you want WPS, enable it here.
//#define ENABLE_WPS

#include <Arduino.h>
#include <ESP8266WiFi.h>
#include <ESP8266WebServer.h>
#include <ESP8266HTTPClient.h>
#include <ESP8266httpUpdate.h>
#include <ESP8266mDNS.h>
#include <WiFiUDP.h>
#include <EEPROM.h>

extern "C" {
  #include "user_interface.h"
}

static const char* __ssid_ap = "unijoysticle";       // SSID for Access Point
static const char __signature[] = "uni";

enum {
    // possible errors. Use nubmer >=2
    ERROR_CANNOT_CONNECT = 2,
    ERROR_MDNS_FAIL = 3,
    ERROR_UDP_FAIL = 4,
};

enum {
    MODE_AP = 0,        // AP, creates the unijoysticle wifi network
    MODE_STA = 1,       // STA, tries to connect to SSID. If it fails, then AP
    MODE_WPS = 2,       // WPS, tries to connect to SSID. If it fails, then WPS, if it fails AP.
};

static const uint8_t DEFAULT_MODE = MODE_AP;
static const uint8_t DEFAULT_INACTIVITY_TIMEOUT = 10;

static const unsigned int localPort = 6464;     // local port to listen for UDP packets
static IPAddress __ipAddress;                   // local IP Address
static uint8_t __mode = DEFAULT_MODE;           // how to connect ?
static uint8_t __inactivityTimeout = DEFAULT_INACTIVITY_TIMEOUT;    // inactivity seconds
static int __lastTimeActivity = 0;              // last time when there was activity
static bool __in_ap_mode = false;               // in AP connection? different than __mode, since
                                                // this is not a "mode" but how the connection was established

static const int INTERNAL_LED = D0; // Amica has two internals LEDs: D0 and D4
static const int __pinsPort0[] = {D0, D1, D2, D3, D4};
static const int __pinsPort1[] = {D5, D6, D7, D8, RX};
static const int TOTAL_PINS = sizeof(__pinsPort0) / sizeof(__pinsPort0[0]);

// how many pushes/presses
static int __joyPushes0[] = {0, 0, 0, 0, 0};
static int __joyPushes1[] = {0, 0, 0, 0, 0};

// how many milliseconds it was used
static int __joyTimeUsed0[] = {0, 0, 0, 0, 0};
static int __joyTimeUsed1[] = {0, 0, 0, 0, 0};

// last time (ms) it was pressed. needed to measure the ms
static int __joyLastTimeUsed0[] = {0, 0, 0, 0, 0};
static int __joyLastTimeUsed1[] = {0, 0, 0, 0, 0};

// last joy state
static uint8_t __lastJoy0 = 0;
static uint8_t __lastJoy1 = 0;

static byte packetBuffer[512];             //buffer to hold incoming and outgoing packets

static WiFiUDP __udp;                           // server for joysticks commands
static ESP8266WebServer __settingsServer(80);   // server for settings


void setup()
{
    // Open serial communications and wait for port to open:
    Serial.begin(115200);
    Serial.setDebugOutput(true);

    EEPROM.begin(256);

    delay(500);

    __inactivityTimeout = getInactivityTimeout();
    __mode = getMode();
    __in_ap_mode = false;

    Serial.printf("\n*** The UniJoystiCle " UNIJOYSTICLE_VERSION " ***\n");
    Serial.printf("\nMode: %d, inactivity timeout:%d\n", __mode, __inactivityTimeout);

    // setting up Station AP
    setupWiFi();
    delay(500);
    printWifiStatus();

    Serial.printf("Udp server started at port: %d\n", localPort);

    delay(2000);

    String mdnsName = getMDNSName();
    Serial.printf("MDNS name: '%s.local'\n", mdnsName.c_str());

    if (MDNS.begin(mdnsName.c_str()))
        Serial.println("MDNS responder started");
    else fatalError(ERROR_MDNS_FAIL);

    if (__udp.begin(localPort))
        Serial.println("UDP server started");
    else fatalError(ERROR_UDP_FAIL);

    createWebServer();
    __settingsServer.begin();
    Serial.println("HTTP server started");

    // advertize mDNS service
    MDNS.addService("unijoysticle", "udp", localPort);
    delay(100);
    MDNS.addService("http", "tcp", 80);
    delay(100);

    for (int i=0; i<TOTAL_PINS; i++)
    {
        pinMode(__pinsPort0[i], OUTPUT);
        digitalWrite(__pinsPort0[i], LOW);
        pinMode(__pinsPort1[i], OUTPUT);
        digitalWrite(__pinsPort1[i], LOW);
    }
}

void loop()
{
    loopUDP();
    __settingsServer.handleClient();
}

static void loopUDP()
{
    // this flag is not really needed, but I don't know if digitalWrite()
    // consumes battery... so we just avoid calling it if not needed
    static bool inactivityActivated = false;
    const int now = millis();

    int noBytes = __udp.parsePacket();
    if (noBytes == 0) {
        // after 48 days of use, this might trigger an invalid condition
        if ((__inactivityTimeout > 0) && 
            ((now - __lastTimeActivity) / 1000.0f) >= __inactivityTimeout &&
            !inactivityActivated
            ) {
            for (int i=0; i<TOTAL_PINS; i++)
            {
                digitalWrite(__pinsPort0[i], LOW);
                digitalWrite(__pinsPort1[i], LOW);
            }

            inactivityActivated = true;
        }
        return;
    }
    inactivityActivated = false;

    // FIXME: if a packet is received, then that count as activity
    // even invalid packets... but invalid packets should be ignored
    // but not a big deal really
    __lastTimeActivity = now;

    String received_command = "";

    if (noBytes == 2)
    {
        // Protocol v1
        // byte 0:
        // LSB Nibble: Control Port: 0 or 1
        // MSB Nibble: 0 Joystick value
        //             1 Mouse (Not supported yet)
        //             2 Paddle (Not supported yet)
        //
        // byte 1:
        // Joystick  bit 0: up
        //           bit 1: down
        //           bit 2: left
        //           bit 3: right
        //           bit 4: fire

        const int* pins;
        int* joyPushes;
        int* joyTimeUsed;
        int* joyLastTimeUsed;
        uint8_t lastJoy;

        __udp.read(packetBuffer,noBytes); // read the packet into the buffer

        if (packetBuffer[0] == 0) {
            pins = __pinsPort0;
            joyPushes = __joyPushes0;
            lastJoy = __lastJoy0;
            joyTimeUsed = __joyTimeUsed0;
            joyLastTimeUsed = __joyLastTimeUsed0;
        } else {
            pins = __pinsPort1;
            joyPushes = __joyPushes1;
            lastJoy = __lastJoy1;
            joyTimeUsed = __joyTimeUsed1;
            joyLastTimeUsed = __joyLastTimeUsed1;
        }

        for (int i=0; i<TOTAL_PINS; i++)
        {
            const uint8_t mask = 1<<i;

            // only if it is different
            if ((lastJoy & mask) != (packetBuffer[1] & mask)) {
                if (packetBuffer[1] & mask) {
                    digitalWrite(pins[i], HIGH);
                    joyPushes[i]++;
                    joyLastTimeUsed[i] = now;
                } else {
                    digitalWrite(pins[i], LOW);
                    joyTimeUsed[i] += (now - joyLastTimeUsed[i]);
                }
            }
        }

        // update last joy
        if (packetBuffer[0] == 0)
            __lastJoy0 = packetBuffer[1];
        else
            __lastJoy1 = packetBuffer[1];
    }
    else if (noBytes == 4)
    {
        // Protocol v2
        // packetBuffer[0] = version
        // packetBuffer[1] = ports enabled
        // packetBuffer[2] = joy1
        // packetBuffer[3] = joy2

        __udp.read(packetBuffer, noBytes); // read the packet into the buffer

        // correct version?
        if (packetBuffer[0] == 2) {
            // joy 1 enabled ?
            if (packetBuffer[1] & 0x1) {
                for (int i=0; i<TOTAL_PINS; i++)
                {
                    const uint8_t mask = 1<<i;
                    // only update if different from last state
                    if ((__lastJoy0 & mask) != (packetBuffer[2] & mask)) {
                        if (packetBuffer[2] & mask) {
                            digitalWrite(__pinsPort0[i], HIGH);
                            __joyPushes0[i]++;
                            __joyLastTimeUsed0[i] = now;
                        } else {
                            digitalWrite(__pinsPort0[i], LOW);
                            __joyTimeUsed0[i] += (now - __joyLastTimeUsed0[i]);
                        }
                    }
                }
                __lastJoy0 = packetBuffer[2];
            }

            // joy 2 enabled ?
            if (packetBuffer[1] & 0x2) {
//                Serial.printf("Received: $%02x (%d)\n", packetBuffer[3], packetBuffer[3]);
                for (int i=0; i<TOTAL_PINS; i++)
                {
                    const uint8_t mask = 1<<i;
                    // only update if different from last state
                    if ((__lastJoy1 & mask) != (packetBuffer[3] & mask)) {
                        if (packetBuffer[3] & mask) {
                            digitalWrite(__pinsPort1[i], HIGH);
                            __joyPushes1[i]++;
                            __joyLastTimeUsed1[i] = now;
                        } else {
                            digitalWrite(__pinsPort1[i], LOW);
                            __joyTimeUsed1[i] += (now - __joyLastTimeUsed1[i]);
                        }
                    }
                }
                __lastJoy1 = packetBuffer[3];
            }
        }
    }
    else
    {
      Serial.println("Invalid packet");
    }
}

static void fatalError(int times)
{
    Serial.println("Fatal error. Reboot please");
    pinMode(INTERNAL_LED, OUTPUT);
    while(1) {
        // report error
        for (int i=0; i<times; i++) {
            delay(400);
            digitalWrite(INTERNAL_LED, LOW);
            delay(400);
            digitalWrite(INTERNAL_LED, HIGH);
        }
        delay(500);
    }
}

static void setupWiFi()
{
    bool ok = false;

    if (__mode == MODE_STA || __mode == MODE_WPS)
        ok = setupSTA();

#ifdef ENABLE_WPS
    if (!ok && __mode == MODE_WPS)
        ok = setupWPS();
#endif // ENABLE_WPS

    // always default to AP if couldn't connect with previous modes
    if (!ok)
        ok = setupAP();
}

static bool setupAP()
{
    delay(100);
    WiFi.mode(WIFI_AP);
    delay(100);

    uint8_t mac[WL_MAC_ADDR_LENGTH];
    WiFi.softAPmacAddress(mac);
    char buf[50];
    memset(buf, 0, sizeof(buf)-1);
    snprintf(buf, sizeof(buf)-1, "%s-%x%x%x",
             __ssid_ap,
             mac[WL_MAC_ADDR_LENGTH-3],
             mac[WL_MAC_ADDR_LENGTH-2],
             mac[WL_MAC_ADDR_LENGTH-1]);

    Serial.printf("Creating AP with SSID='%s'...",buf);
    bool success = false;
    while(!success) {
        if ((success=WiFi.softAP(buf))) {
            Serial.println("OK");
        } else {
            Serial.println("Error");
            delay(1000);
        }
    }

    __in_ap_mode = true;
    return true;
}

static bool setupSTA()
{
    char ssid[128];
    char pass[128];
    readCredentials(ssid, pass);

    Serial.printf("Trying to connect to %s...\n", ssid);
    WiFi.mode(WIFI_STA);
    WiFi.begin(ssid, pass);
    return (WiFi.waitForConnectResult() == WL_CONNECTED);
}

#ifdef ENABLE_WPS
static bool setupWPS()
{
    // Mode must be WIFI_STA, but it is already in that mode
    Serial.println("Trying to connect using WPS...");
    bool wpsSuccess = WiFi.beginWPSConfig();
    if(wpsSuccess) {
        // in case of a timeout we might have an empty ssid
        String newSSID = WiFi.SSID();
        if(newSSID.length() > 0) {
            Serial.printf("Connected to SSID '%s'\n", newSSID.c_str());
            Serial.printf("Password: %s\n", WiFi.psk().c_str());
            saveCredentials(WiFi.SSID(), WiFi.psk());
            delay(500);
        } else {
            Serial.println("WPS failed");
            wpsSuccess = false;
        }
    }

    if (!wpsSuccess) {
        // Issue #1845: https://github.com/esp8266/Arduino/issues/1845
        delay(500);
        wifi_wps_disable();
    }
    return wpsSuccess;
}
#endif // ENABLE_WPS

static void printWifiStatus()
{
    if (__in_ap_mode) {
        Serial.print("AP Station #: ");
        Serial.println(WiFi.softAPgetStationNum());
        // print your WiFi shield's IP address:
        __ipAddress = WiFi.softAPIP();
        Serial.print("Local IP Address: ");
        Serial.println(__ipAddress);
    }
    else
    {
        // print the SSID of the network you're attached to:
        Serial.printf("SSID: %s\n", WiFi.SSID().c_str());
        // print your WiFi shield's IP address:
        __ipAddress = WiFi.localIP();
        Serial.print("Local IP Address: ");
        Serial.println(__ipAddress);
    }
}

//
// EEPROM struct
//  0-2: "uni"
//    3: mode: 0 = AP, creates the unijoysticle wifi network
//             1 = STA, tries to connect to SSID. If it fails, then AP
//             2 = WPS, tries to connect to SSID. If it fails, then WPS, if it fails AP.
//    4: inactivity seconds
//             0 = don't check innactivity
//             any other value = how many seconds should pass before reseting the lines
//  5: version. 0 = first version
//              1 = includes MDNS name (128-160)
//  6-7: reserved
//  asciiz: SSID
//  asciiz: password
//  128-160: asciiz: MDNS name. default: "unijoysticle"
//
static bool isValidEEPROM()
{
    bool failed = false;
    for (int i=0; i<3; ++i) {
        char c = EEPROM.read(i);
        failed |= (c != __signature[i]);
    }
    return !failed;
}

static void setDefaultValues()
{
    Serial.println("setDefaultValues()");

    for (int i=0; i<3; i++) {
        EEPROM.write(i, __signature[i]);
    }
    // Mode
    EEPROM.write(3, DEFAULT_MODE);
    // Inactivity timeout
    EEPROM.write(4, DEFAULT_INACTIVITY_TIMEOUT);

    // format version:
    EEPROM.write(5, 1);

    // unused
    EEPROM.write(6, 0);
    EEPROM.write(7, 0);

    // SSID name (asciiz)
    EEPROM.write(8, 0);
    // SSDI passwrod (asciiz)
    EEPROM.write(9, 0);

    static const char* unistr = "unijoysticle";
    for (int i=0; i<strlen(unistr); i++)
        EEPROM.write(128+i, unistr[i]);
    EEPROM.write(128+strlen(unistr), 0);

    EEPROM.commit();
}

static void readCredentials(char* ssid, char* pass)
{

#if 0
    char tmp[513];
    for (int i=0; i<512; i++)
        tmp[i] = EEPROM.read(i);
    Serial.printf("EEPROM signature: %s\n", tmp);

    for (int i=0;i<32;i++) {
        Serial.printf("%2x %2x %2x %2x %2x %2x %2x %2x - "
                      ,tmp[i*16 + 0]
                      ,tmp[i*16 + 1]
                      ,tmp[i*16 + 2]
                      ,tmp[i*16 + 3]
                      ,tmp[i*16 + 4]
                      ,tmp[i*16 + 5]
                      ,tmp[i*16 + 6]
                      ,tmp[i*16 + 7]);
        Serial.printf("%2x %2x %2x %2x %2x %2x %2x %2x\n"
                      ,tmp[i*16 + 8]
                      ,tmp[i*16 + 9]
                      ,tmp[i*16 + 10]
                      ,tmp[i*16 + 11]
                      ,tmp[i*16 + 12]
                      ,tmp[i*16 + 13]
                      ,tmp[i*16 + 14]
                      ,tmp[i*16 + 15]);
    }
#endif

    if (!isValidEEPROM()) {
        Serial.printf("EEPROM signature failed: not 'uni'\n");
        ssid[0] = 0;
        pass[0] = 0;
        setDefaultValues();
        return;
    }

    int idx=8;
    for(int i=0;;i++) {
        ssid[i] = EEPROM.read(idx++);
        if (ssid[i] == 0)
            break;
    }

    for(int i=0;;i++) {
        pass[i] = EEPROM.read(idx++);
        if (pass[i] == 0)
            break;
    }
    Serial.printf("EEPROM credentials: ssid: %s, pass: %s\n", ssid, pass);
}

static void saveCredentials(const String& ssid, const String& pass)
{
    int idx = 8;

    for (int i=0; i<ssid.length(); ++i) {
        EEPROM.write(idx, ssid[i]);
        idx++;
    }

    EEPROM.write(idx, 0);
    idx++;

    for (int i=0; i<pass.length(); ++i) {
        EEPROM.write(idx, pass[i]);
        idx++;
    }
    EEPROM.write(idx, 0);
    EEPROM.commit();
}

static uint8_t getMode()
{
    if (!isValidEEPROM()) {
        setDefaultValues();
        return MODE_AP;
    }
    uint8_t mode = EEPROM.read(3);
    return mode;
}

static void setMode(uint8_t mode)
{
    if (!isValidEEPROM()) {
        setDefaultValues();
    }
    EEPROM.write(3, mode);
    EEPROM.commit();
}

static String getMDNSName()
{
    if (!isValidEEPROM()) {
        setDefaultValues();
    }

    // Version 0?
    if (EEPROM.read(5) == 0) {
        return String("unijoysticle");
    }

    // max len is 32
    char buf[64];

    const int idx=128;
    for(int i=0;;i++) {
        buf[i] = EEPROM.read(idx+i);
        if (buf[i] == 0)
            break;
        if (i>32) {
            Serial.println("Error: getMDNSName()");
            buf[i] = 0;
            break;
        }
    }
    return String(buf);
}

static void setMDNSName(const String& name)
{
    int idx = 128;

    for (int i=0; i<name.length(); ++i) {
        EEPROM.write(idx, name[i]);
        idx++;
    }

    EEPROM.write(idx, 0);

    // make sure it is version 1
    EEPROM.write(5,1);

    EEPROM.commit();
}

// in seconds
static uint8_t getInactivityTimeout()
{
    if (!isValidEEPROM()) {
        setDefaultValues();
        return 0;
    }
    return EEPROM.read(4);
}

static void setInactivityTimeout(uint8_t seconds)
{
    if (!isValidEEPROM()) {
        setDefaultValues();
    }
    EEPROM.write(4, seconds);
    EEPROM.commit();
}


//
// Settings
//
void createWebServer()
{
    static const char *htmlraw = R"html(<html>
<head><title>UniJoystiCle WiFi setup</title></head>
<body>
<h1>The UniJoystiCle WiFi setup</h1>
<h2>Stats</h2>
<ul>
 <li>Firmware: %s</li>
 <li>IP Address: %d.%d.%d.%d</li>
 <li>Name: %s</li>
 <li>SSID: %s</li>
 <li>Joy #1 (ms / # movements):</li>
 <ul>
  <li>Up: %dms / %d</li>
  <li>Down: %dms / %d</li>
  <li>Left: %dms / %d</li>
  <li>Right: %dms / %d</li>
  <li>Fire: %dms / %d</li>
 </ul>
 <li>Joy #2 (ms / # movements):</li>
 <ul>
  <li>Up: %dms / %d</li>
  <li>Down: %dms / %d</li>
  <li>Left: %dms / %d</li>
  <li>Right: %dms / %d</li>
  <li>Fire: %dms / %d</li>
 </ul>
</ul>
<form method='get' action='resetstats'>
 <input type='submit' value='Reset Joy Stats'>
</form>
<h2>Settings</h2>
<h4>Set WiFi mode:</h4>
<form method='get' action='mode'>
 <input type='radio' name='mode' value='0' %s> Access Point mode (AP)<br>
 <input type='radio' name='mode' value='1' %s> Station mode (STA)<br>
 <input type='radio' name='mode' value='2' %s> Station mode + WPS (STA+WPS)<br>
 <input type='submit' value='Submit'>
</form>
<small>Reboot to apply changes</small>
<br><p>Mode description:</p>
<ul>
 <li>AP: creates its own WiFi network. The SSID will start with <i>unijoysticle-</i></li>
 <li>STA: Tries to connect to a WiFi network using the specified SSID/password. If it fails, it will go into AP mode</li>
 <li>STA+WPS: Tries to connect to a WiFi network by using <a href='https://en.wikipedia.org/wiki/Wi-Fi_Protected_Setup'>WPS</a>. If it fails it will go into AP mode</li>
</ul>
<h4>Set SSID/Password (to be used when in STA mode):</h4>
<form method='get' action='setting'>
 <label>SSID: </label><input name='ssid' length=32/>
 <label>Password: </label><input name='pass' length=64/><br/>
 <input type='submit' value='Submit'>
</form>
<small>Reboot to apply changes</small>

<h4>Inactivity timeout:</h4>
<form method='get' action='inactivity'>
 <label>Inactivity Timeout:</label><input type="text" name="inactivity" onkeypress='return event.charCode >= 48 && event.charCode <= 57' value="%d">(in seconds, from 0 to 255)</input><br/>
 <input type='submit' value='Submit'>
</form>
After how many seconds of inactivity, should it reset the joysticks. "0" disables this feature. Useful in case one of the joystick lines, unintentinally, is left closed (on).

<h4>MDNS name:</h4>
<form method='get' action='name'>
 <label>MDNS name:</label><input name="name" value="%s" length=32>.local (suffix ".local" is added automatically)</input><br/>
 <input type='submit' value='Submit'>
</form>
<small>Reboot to apply changes</small>

<h4>Reboot device:</h4><form method='get' action='restart'><input type='submit' value='Reboot'></form>

<h4>Upgrade firmware:</h4><a href="/upgrade">Upgrade page</a><hr>
</body></html>
)html";

    static const char *htmlredirectok = R"html(<html>
<head>
 <meta http-equiv="refresh" content="1; url=/" />
</head>
<body>Success</body>
</html>
)html";

    static const char *htmlredirecterr = R"html(<html>
<head>
 <meta http-equiv="refresh" content="1; url=/" />
</head>
<body>Error</body>
</html>
)html";

    static const char* htmlupgradeconfirm = R"html(<html>
<h1>Firmware upgrade:</h1>
<p>You are about to upgrade the UniJoystiCle WiFi device's firmware.</p>

<ul>
  <li>Current firmware version: %s</li>
  <li>Latest stable firmware version: <a href="http://ricardoquesada.github.io/unijoysticle/bin/LATEST_VERSION.txt">LATEST_VERSION</a></li>
</ul>

<p>As a backup plan (should the worse happen), please read the following:
<a href="https://github.com/ricardoquesada/unijoysticle/blob/master/DOCUMENTATION.md#installing-the-firmware">Installing the firmware</a>
</p>
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

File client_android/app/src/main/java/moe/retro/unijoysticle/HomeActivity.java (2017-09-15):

/*
 * Copyright (C) 2016 Ricardo Quesada
 *
 * Licensed under the Apache License, Version 2.0 (the "License");
 * you may not use this file except in compliance with the License.
 * You may obtain a copy of the License at
 *
 *      http://www.apache.org/licenses/LICENSE-2.0
 *
 * Unless required by applicable law or agreed to in writing, software
 * distributed under the License is distributed on an "AS IS" BASIS,
 * WITHOUT WARRANTIES OR CONDITIONS OF ANY KIND, either express or implied.
 * See the License for the specific language governing permissions and
 * limitations under the License.
 */


package moe.retro.unijoysticle;

import android.os.Bundle;
import android.view.View;
import android.widget.AdapterView;
import android.widget.ArrayAdapter;
import android.widget.Button;
import android.widget.CompoundButton;
import android.widget.SeekBar;
import android.widget.Spinner;
import android.widget.Switch;
import android.widget.TextView;

import java.util.concurrent.Executors;
import java.util.concurrent.ScheduledExecutorService;
import java.util.concurrent.TimeUnit;

import moe.retro.unijoysticle.unijosyticle.R;

public class HomeActivity extends BaseActivity implements
        SeekBar.OnSeekBarChangeListener, View.OnClickListener, Spinner.OnItemSelectedListener, CompoundButton.OnCheckedChangeListener {

    private static final String TAG = HomeActivity.class.getSimpleName();

    private TextView mValueText;
    private Boolean mFirstTime = true;
    private boolean mClearJoyState = false;

    private enum HomeCommands {
        NOTHING((byte)0),
        SONG_0((byte)1),
        SONG_1((byte)2),
        SONG_2((byte)3),
        SONG_3((byte)4),
        SONG_4((byte)5),
        SONG_5((byte)6),
        SONG_6((byte)7),
        SONG_7((byte)8),
        SONG_8((byte)9),

        RESERVED_0((byte)10),

        SONG_STOP((byte)11),
        SONG_PLAY((byte)12),
        SONG_PAUSE((byte)13),
        SONG_RESUME((byte)14),
        SONG_NEXT((byte)15),
        SONG_PREV((byte)16),
        DIMMER_0((byte)17),
        DIMMER_25((byte)18),
        DIMMER_50((byte)19),
        DIMMER_75((byte)20),
        DIMMER_100((byte)21),
        ALARM_OFF((byte)22),
        ALARM_ON((byte)23),

        RESERVED_2((byte)24),
        RESERVED_3((byte)25),
        RESERVED_4((byte)26),
        RESERVED_5((byte)27),
        RESERVED_6((byte)28),
        RESERVED_7((byte)29),
        RESERVED_8((byte)30),
        RESERVED_9((byte)31);

        private final byte value;
        HomeCommands(byte v) {
            this.value = v;
        }
        public byte getValue() {
            return this.value;
        }
    }

    @Override
    public void onCreate(Bundle savedInstanceState) {
        super.onCreate(savedInstanceState);

        setTitle(getString(R.string.action_bar_title_home));

        setContentView(R.layout.activity_home);

        // dimmer
        mValueText = (TextView) findViewById(R.id.textView_dimmer);
        SeekBar seekBar = (SeekBar) findViewById(R.id.seekBar_dimmer);
        seekBar.setOnSeekBarChangeListener(this);

        // Songs
        Button buttonPlay = (Button) findViewById(R.id.button_play);
        Button buttonStop = (Button) findViewById(R.id.button_stop);
        buttonPlay.setOnClickListener(this);
        buttonStop.setOnClickListener(this);

        Spinner spinnerSong = (Spinner) findViewById(R.id.spinner_songs);
        spinnerSong.setOnItemSelectedListener(this);
        // Create an ArrayAdapter using the string array and a default spinner layout
        ArrayAdapter<CharSequence> adapter = ArrayAdapter.createFromResource(this,
                R.array.songs, android.R.layout.simple_spinner_item);
        // Specify the layout to use when the list of choices appears
        adapter.setDropDownViewResource(android.R.layout.simple_spinner_dropdown_item);
        // Apply the adapter to the spinner
        spinnerSong.setAdapter(adapter);

        // alarm
        Switch alarmSwitch = (Switch) findViewById(R.id.switch_alarm);
        alarmSwitch.setOnCheckedChangeListener(this);


        mProtoVersion = 2;
        mProtoHeader.joyState1 = 0;     // reset joystick values
        mProtoHeader.joyState2 = 0;
        mProtoHeader.joyControl = 3;    // both joyticks (1 and 2)


        // schedule a handler every 60 per second
        ScheduledExecutorService scheduleTaskExecutor = Executors.newScheduledThreadPool(2);
        scheduleTaskExecutor.scheduleAtFixedRate(new Runnable() {
            public void run() {
                try {
                    if (mClearJoyState) {
                        Thread.sleep(160);
                        mProtoHeader.joyState2 = 0;
                        sendJoyState();
                        mClearJoyState = false;
                    }

                } catch (InterruptedException e) {
                    e.printStackTrace();
                }
            }
        }, 0, 16, TimeUnit.MILLISECONDS);       // ~60Hz

    }

    //
    // Dimmer
    //

    // OnSeekBarChangeListener methods :
    @Override
    public void onProgressChanged(SeekBar seek, int value, boolean fromTouch)
    {
        String values[] = {"Off", "25%", "50%", "75%", "100%"};
        HomeCommands[] commands = {HomeCommands.DIMMER_0,
                HomeCommands.DIMMER_25,
                HomeCommands.DIMMER_50,
                HomeCommands.DIMMER_75,
                HomeCommands.DIMMER_100};
        mValueText.setText(values[value]);

        mProtoHeader.joyState2 = commands[value].getValue();
        sendJoyState();
        mClearJoyState = true;
    }
    @Override
    public void onStartTrackingTouch(SeekBar seek) {}
    @Override
    public void onStopTrackingTouch(SeekBar seek) {}


    //
    // Songs
    //
    @Override
    public void onClick(View v) {
        switch(v.getId()) {
            case R.id.button_play:
                mProtoHeader.joyState2 = HomeCommands.SONG_PLAY.getValue();
                break;
            case R.id.button_stop:
                mProtoHeader.joyState2 = HomeCommands.SONG_STOP.getValue();
                break;
        }
        sendJoyState();
        mClearJoyState = true;
    }

    @Override
    public void onCheckedChanged(CompoundButton compoundButton, boolean b) {
        if (b) {
            mProtoHeader.joyState2 = HomeCommands.ALARM_ON.getValue();
        } else {
            mProtoHeader.joyState2 = HomeCommands.ALARM_OFF.getValue();
        }
        sendJoyState();
        mClearJoyState = true;
    }


    @Override
    public void onItemSelected(AdapterView<?> adapterView, View v, int i, long l) {

        // ignore first time since this will be called right after selecting the HomeActivity
        if (!mFirstTime) {
            mProtoHeader.joyState2 = (byte) ((byte) i + 1);
            sendJoyState();
            mClearJoyState = true;
        }
        mFirstTime = false;
    }

    @Override
    public void onNothingSelected(AdapterView<?> adapterView) {
    }
}

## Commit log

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2016-04-05 feat: add back button to different scenes
2016-04-05 feat: add schematic
    [unijoysticle.fzz]
2016-04-05 docs: docs in the schematic
    [unijoysticle.fzz]
2016-04-05 docs: correct name for BB
    [unijoysticle.fzz]
2016-04-05 docs: adds ™ to Uni-Joysti-Cle
    [unijoysticle.fzz]
2016-04-06 fix: PCB and Schematic looks better but not finished
    [unijoysticle.fzz]
2016-04-06 fixes in schematic
    [unijoysticle.fzz]
2016-04-14 fix: make it compatible with Arduino IDE
    [firmware.ino]
2016-04-14 fix: add delay so that ip address can be displayed
    [firmware.ino]
2016-04-19 feat: add up/down support as well
    uses `userRotation` instead of the accelerometer. data is more reliable.
2016-04-19 feat: add support for button
    a violent movement upwards will trigger the button
2016-04-20 fix: report error by flashing internal LED
    [firmware.ino]
2016-04-22 fix: make it more robust
    - reset joytick when leaving (to avoid having the joystick pressed)
    - d0-d4, d5-d9 are the new GPIOs for NodeMCU
    - and other minor fixes
    [firmware.ino]
2016-04-22 feat: breadboard v0.2
    [unijoysticle.fzz]
2016-04-24 new: add schematic for v0.2
    [unijoysticle.fzz]
2016-04-25 fix: little costemic fixes in schematic + breadboard view
    [unijoysticle.fzz]
2016-04-26 Adds Eagle files
    [unijoysticle.brd, unijoysticle.fzz, unijoysticle.sch]
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2016-04-29 fix: schematic & board fixed
    [unijoysticle.brd, unijoysticle.sch]
2016-04-29 fix: board fixes
    [unijoysticle.brd, unijoysticle.sch]
2016-04-29 fix: ports in separated by 30.6mm from pin to pin
    [unijoysticle.brd]
2016-04-29 fix: new design
    [unijoysticle.brd, unijoysticle.sch]
2016-04-30 fix: yet another pcb version. smaller, better design
    [unijoysticle.brd, unijoysticle.sch]
2016-05-03 fix: adds .cam file to generate gerbert files
    [unijoysticle.brd, unijoysticle.sch]
2016-05-31 fix: new images for schem and board
2016-06-14 fix: esp8622 schematic: ics with joy power. new dc jack barrel
    [unijoysticle.brd, unijoysticle.sch]
2016-06-16 fix: joy pin #8 are connected
    Not really needed since they are already connected inside the C64,
    but usuful to have them connected in the board
    [unijoysticle.brd, unijoysticle.sch]
2016-06-20 fix: schematic doesn't use ESP8266 VCC
    and uses Copper Pour
    [unijoysticle.brd, unijoysticle.sch]
2016-06-20 bitmap in schematic
    [unijoysticle.brd]
2016-07-07 iOS Client: fixes
    - UniJoystiCle mode shows dpad instead of bits
    - calibrated for idling and jumping
    [firmware.ino]
2016-07-29 add "handicap" property
    and new algorithm to simulate wheel rotation.
    uses angular position instead of raw acceleration
2016-07-29 don't print the angle
2016-08-03 PCB fixes: reduced realstate
    uses new DB9 connectors without the uneeded holes.
    compabible with Commodore 128D and SX-64
    [unijoysticle.brd, unijoysticle.sch]
2016-08-04 using wemos d1 mini instead of NodeMCU
    smaller realstate PCB making it under 5cm by 5cm.
    cheaper to order from certain providers
    [unijoysticle.brd, unijoysticle.sch]
2016-08-05 sharing the same ground for all components
    [unijoysticle.brd, unijoysticle.sch]
2016-08-05 removed diode
    apparently not needed:
    http://forum.wemos.cc/topic/343/power-the-board-with-both-usb-and-vin-pin-at-the-same-time
    [unijoysticle.brd, unijoysticle.sch]
2016-08-11 simplified board...
    no more barrel jack for the D1 Mini version
    [unijoysticle.brd, unijoysticle.sch]
2016-08-11 circular borders
    [unijoysticle.brd]
2016-08-11 cam file updated with outline
    [unijoysticle.brd]
2016-08-15 fix: add two vias in PCB
    [unijoysticle.brd]
2016-08-15 fix: slightly better PCB design.
    chip + D1 are placed a little bit better makeing it possible
    to have a better routing
    [unijoysticle.brd]
2016-08-15 fix: PCB: removed deprecated Fritzing files.
    and updates board png image
    [unijoysticle.fzz]
2016-08-15 fix: Schematic PNG image updated
2016-08-20 fix: ios_client: button B XOR arrow up
2016-08-24 feat: ios_client: possibility to switch buttons A and B
    also fix button rendering
2016-08-24 fix: ios_client: Switch A/B -> Swap A/B
2016-09-04 android client: new icon and buttonB and swapAB work
2016-09-04 android client: resubmitted
    id is: moe.retro.unijosyticle (one unijosyticle)
    floating button: goes to documentation
    using correct title bar in actionbar
    doesn't show status bar
2016-09-07 feat: a c64 prg to test the unijosyticle
    includes instructions
    [unijoysticle_test.cfg]
2016-09-09 feat: Commando Mode
    Control both joysticks with one game controller
    It is called Commando Mode because you can play an unmodified
    Commando game and fire with Button A, and thorw granedes with
    Button B!!
2016-09-10 fix: android client: hide Gyruss radio button...
    ...until it is implemented correctly
2016-09-13 ios/android client: send state twice per change
    and not 60 times per second. saves battery life!
    Also fixes joystick movements in android.
2016-09-14 board: add 5V barrel jack to board (again)
    [unijoysticle.brd, unijoysticle.sch]
2016-09-14 board: missing via and better labels
    [unijoysticle.brd, unijoysticle.sch]
2016-09-14 docs: more info about current
2016-09-16 ios client: fix: improves iCade support
    Buttons A and D are Fire (not only A)
    Buttons B and C are Jump (not only B)
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2016-09-17 android client: add analytics
    to see what is the most popular mode
    [app_tracker.xml]
2016-09-18 docs: documentation mA power use fixes
2016-09-19 client android / firmware: fixes
    client android: display error dialog if can't resolve server name
    firmware: added code for WPS support. disabled by default
    [firmware.ino]
2016-09-20 firmware: fix: no compile-time options
    everything can be changed in runtime by setting certain values
    in the EEPROM. No possible yet to change those values, but
    will be enabled soon via TCP
    [firmware.ino]
2016-09-20 firmware: small fixes in MDNS
    [firmware.ino]
2016-09-21 firmware: adds stats
    how many ms the buttons were used / how many presses
2016-09-21 firmware: reset joy stats + more bug fixes
    [firmware.ino]
2016-09-23 ios client: adds Stats & SEttings for WiFi device
2016-09-23 android client: Server -> WiFi device
2016-09-23 android client: fixes issue #4
    onPostExecute() only gets called on the UI thread.
    but if we block the UI thread it won't be called, and we won't
    have the result that we need...
2016-09-24 android client: does not crash when opening...
    stats from settings when wifi device address is 192....
2016-09-24 firmware: fetch firmware from correct localtion
    [firmware.ino]
2016-09-24 firmware: correct URL for upgrade
    [firmware.ino]
2016-09-25 docs: more info about the current
2016-10-03 docs: better power consumtion
2016-10-07 schematic: adds diode again
    I don't know if it is really needed, but it is scary
    to see the c64 LED on, even if the computer is off
    when the unijosyticle is being powered by USB,
    but externally connected to the datassette port
    [unijoysticle.brd, unijoysticle.sch]
2016-10-07 board: adds 3 vias
    [unijoysticle.brd]
2016-10-07 board: via is cenetered
    [unijoysticle.brd]
2016-10-07 board: label "unijoysticle" better position
    [unijoysticle.brd]
2016-10-07 board: longer pads for wemos
    [unijoysticle.brd, unijoysticle.sch]
2016-10-19 desktop client: disable button/settings
2016-10-20 desktop client: keyboard works ok
    swap and button B work as expected
2016-10-30 android client: home fixes
    alarm switch works
    fix play/stop buttons
    [HomeActivity.java]
2016-11-07 ios client: maps X and Y buttons to joy1 down/right
2016-11-07 docs: changelog update for buttons X and Y in Commando mode
2016-11-08 firmware: mdns name fixed
    [firmware.ino]
2016-11-11 schematic: add datasette connector
    [datasette_connector.brd, datasette_connector.sch]
2016-11-11 schematic: datasette port bottom names fix
    [datasette_connector.brd]
2016-11-12 board: datasette: adds panelized version
    [datasette_connector.brd, datasette_connector_panelized.brd]
2016-11-14 laytout: datasette connect panelized fixes
    gap has 1mm instead of 0.6mm since Seeed Studio doesn't support it
    [datasette_connector_panelized.brd]
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2017-01-04 esp32: kind of works pot + udp server
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2017-01-06 firmware esp32: doing more experiments
    still NEGEDGE doesn't work as expected.
    Not sure whether the bug is in my code or in the IDF
    [main.c]
2017-01-07 esp32: fixes to make it work with the inverter
    [main.c]
2017-01-08 esp32: more trial and error
    [main.c]
2017-01-17 reorganized schematic directory
    [datasette_connector.brd, datasette_connector.sch, datasette_connector_panelized.brd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]
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2017-01-24 esp32: works... sort of... only one pot
    the thing is the espthing 32 doesn't want to connect :(
    [main.c]
2017-06-18 WIP: digi-pot driver for esp32 based unijoysticle
    [app_tracker.xml]
2017-09-15 android project fixes
    upgrades to sdk 26 and other minor changes
    [HomeActivity.java]
2019-01-06 v2: PoC. add hid-gamepad
    move old esp32 to old folder
2019-01-06 add localhost test.
    easier to test everything in localhost and in esp32.
    once ready, should be flashed to esp32
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2019-01-07 template to compile sdk for esp32 + btstack
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2019-01-14 ios: compiles, but crashes with thread concurrent bug
    this is a new features in swift 4
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2019-01-19 esp32: shuffling code...
    cleaning up code... adding gap query
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2019-01-20 esp32: descriptor len fixes. 16-bits now instead of 8
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2019-01-21 esp32: error check
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2019-01-21 esp32: spaghetti code, bug multiple connection/reconnection/discoveries works
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2019-01-22 esp32: copy firmware to esp32...
    works on the ESP32 as well on the PC
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2019-01-23 esp32: fix some connection / reconnection issues on certain devices
2019-01-25 esp32: recognizes mouses and tries to connect to them
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2019-01-27 esp32: "correctly" parses hat and x,y,z...
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2019-01-28 esp32: add support for TV control remote (at least Amazon TV)
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2019-01-29 esp32: crash on device... trying to figure out what is happening
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2019-01-30 esp32: add suport for page7 usage0
    reserved... ignored
2019-01-30 esp32: sdkconfig
    use 80Mhz by default.
    UART0 GPIO1 and GPIO3 (which are the default)... tryied using
    different ones, but as expected, no output.
    I need GPIO3 free... we'll see
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2019-01-31 esp32: mini refactor.
    my_hid_device in its own file
2019-01-31 esp32: another mini refactor...
    moved parsing stuff to "hid_parser"
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2019-01-31 esp32: button "b" is "jump"... triggers up movement
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2019-02-01 esp32: fixes while processing axis
2019-02-01 esp32: cleaner fixes
2019-02-02 esp32: cleaning code... still too much code to clean
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2019-02-02 esp32: minor fixes plus using esp-idf v3.1.2 instead of master
2019-02-02 esp32: sanity checks. don't accept packets if bt is not ready
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2019-02-02 esp32: missing ; oops
2019-02-02 esp32: all printf disabled... watchdog got triggered
    'Task watchdog got triggered'. disabling all printf()
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2019-02-03 esp32: better logging (from unijoysticle_config.h)
    and only remove link_keys on certain errors
2019-02-03 esp32: by default, VERBOSE_LOGGING until we are production ready
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2019-02-06 esp32: more resolution for axis
    and other mouse fixes
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

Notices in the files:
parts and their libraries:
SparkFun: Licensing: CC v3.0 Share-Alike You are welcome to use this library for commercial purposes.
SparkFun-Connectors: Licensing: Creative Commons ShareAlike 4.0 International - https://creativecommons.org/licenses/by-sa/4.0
